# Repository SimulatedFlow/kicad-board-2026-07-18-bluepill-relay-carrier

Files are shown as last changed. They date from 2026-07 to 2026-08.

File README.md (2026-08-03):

# 2026-07-18-bluepill-relay-carrier

<!-- SF-STORE-BLOCK:BEGIN -->
## 🛒 Source-available — see before you buy

This repository contains the **full design files** of a commercial hardware board. It is **source-available, not open source**: read it, evaluate it, then buy a license to use it. See **LICENSE.md (source-available, purchase required)**.

**Get it / Buy:**
- eBay store — all our boards and PCB art: https://www.ebay.de/usr/simula-9
- Merch shop (dev & gaming): https://simulatedflow.myspreadshop.de
- Merch shop (Synthetica / EDM): https://synthetica.myspreadshop.de
- Direct / invoice (Simulated Flow UG): simulatedflow@gmail.com

_This board has no eBay item number of its own listed here — the store link above holds all current listings._

### 📬 **Free Board Documentation & Firmware Pack**

Schematics, BOMs and example-firmware docs for our STM32 carrier boards. Get it by joining the newsletter — plus a heads-up when something new ships. Double opt-in, unsubscribe in one click, no address sharing.

👉 **[Get the free pack](https://simulatedflow.teufel-engineering.com/newsletter/hardware/?q=gh)**

_© 2026 Simulated Flow UG. All rights reserved._
<!-- SF-STORE-BLOCK:END -->

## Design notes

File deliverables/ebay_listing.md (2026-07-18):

# BluePill-Relay-Carrier - Leerplatine fuer STM32 Bluepill (handloetbar, THT-Bausatz-Basis)

Robuste 2-Kanal-Relaisträgerplatine für die STM32 Bluepill mit Sensor-Schnittstelle und galvanischer Absicherung.

## Highlights
- Komplett von Hand loetbar (THT / grosse Bauteile, kein SMD-Feinpitch)
- Passt direkt auf die STM32 'Bluepill' (2x 20-Pin-Buchsenleiste, 22,86 mm Reihenabstand)
- Schraubklemmen am Platinenrand - Kabel sauber nach aussen
- 4x M3-Befestigungsbohrungen fuer gaengige Gehaeuse
- 4-lagig (durchgehende GND- + Versorgungs-Plane, stoerarm/EMV-freundlich)

**Passendes Gehaeuse:** 80x70mm DIN-Hutschienen-Gehäuse (z. B. CamdenBoss CNMB/3)

## Einsatzzweck
Existierende Trägerplatinen sind oft überladene Alleskönner oder billige Steckbrett-Kopien. Dieses Board bietet Bastlern eine saubere, extrem robuste und handlötbare Hutschienen-Plattform für zwei Relais ohne Kabelsalat.

## Bestueckung (ca. 21 Bauteile laut Stueckliste)
- C1: 100uF (x1)
- C2: 100nF (x1)
- D1: 1N4007 (x1)
- D2: 1N4007 (x1)
- D3: 1N5819 (x1)
- D4: LED_RED (x1)
- D5: LED_GRN (x1)
- J1: 5V_IN (x1)
- J2: RY1_OUT (x1)
- J3: RY2_OUT (x1)
- J4: SENSOR (x1)
- Q1: 2N3904 (x1)
- Q2: 2N3904 (x1)
- R1: 1k (x1)
- R2: 1k (x1)
- R3: 330 (x1)
- R4: 330 (x1)
- RY1: SRD-05VDC (x1)
- RY2: SRD-05VDC (x1)
- U1: Bluepill_L (x1)
- U2: Bluepill_R (x1)

## Lieferumfang
- 1x unbestueckte Leiterplatte (Fertigung auf Bestellung via PCBWay)
- Schaltplan als PDF + Bestueckungsliste (BOM als CSV) zum Download

**Preis:** 14.9 EUR (unbestueckte Leerplatine, zzgl. Versand)

Fertigung auf Bestellung - Lieferzeit nach PCBWay-Produktion. Gewerblicher Verkauf durch Simulated Flow UG: gesetzliches Widerrufsrecht und Gewaehrleistung gemaess AGB/Impressum. Versand als versicherter Warenversand.

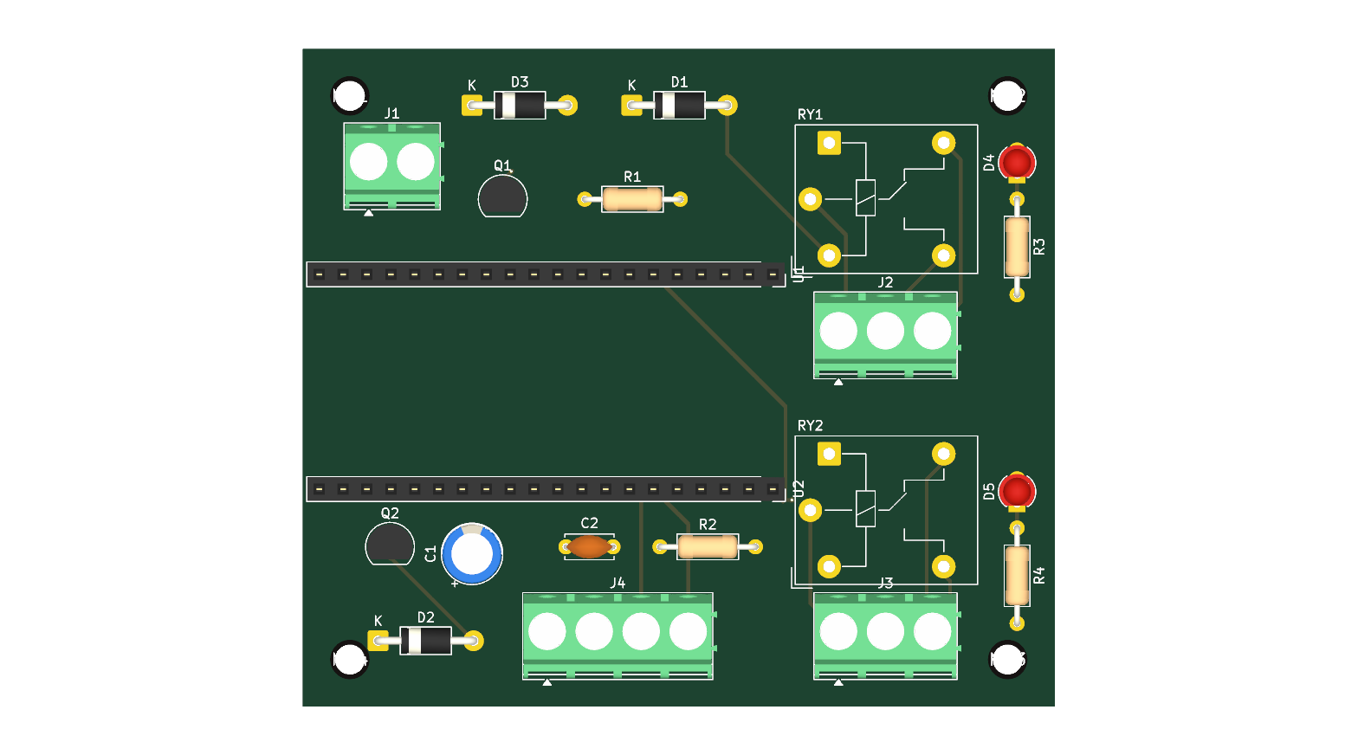
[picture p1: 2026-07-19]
deliverables/render_top.png

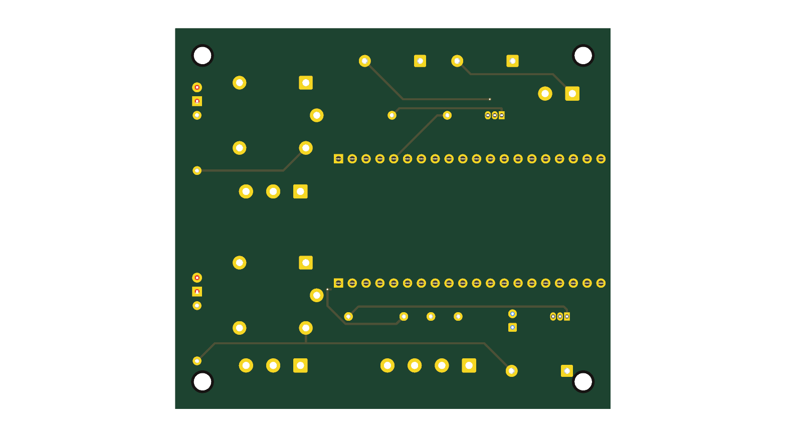
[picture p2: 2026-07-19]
deliverables/render_bottom.png

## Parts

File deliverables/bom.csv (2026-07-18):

Refs | Value | Footprint | Qty | DNP
C1 | 100uF | Capacitor_THT:CP_Radial_D6.3mm_P2.50mm | 1
C2 | 100nF | Capacitor_THT:C_Disc_D5.0mm_W2.5mm_P5.00mm | 1
D1 | 1N4007 | Diode_THT:D_DO-41_SOD81_P10.16mm_Horizontal | 1
D2 | 1N4007 | Diode_THT:D_DO-41_SOD81_P10.16mm_Horizontal | 1
D3 | 1N5819 | Diode_THT:D_DO-41_SOD81_P10.16mm_Horizontal | 1
D4 | LED_RED | LED_THT:LED_D3.0mm | 1
D5 | LED_GRN | LED_THT:LED_D3.0mm | 1
J1 | 5V_IN | TerminalBlock_Phoenix:TerminalBlock_Phoenix_PT-1,5-2-5.0-H_1x02_P5.00mm_Horizontal | 1
J2 | RY1_OUT | TerminalBlock_Phoenix:TerminalBlock_Phoenix_PT-1,5-3-5.0-H_1x03_P5.00mm_Horizontal | 1
J3 | RY2_OUT | TerminalBlock_Phoenix:TerminalBlock_Phoenix_PT-1,5-3-5.0-H_1x03_P5.00mm_Horizontal | 1
J4 | SENSOR | TerminalBlock_Phoenix:TerminalBlock_Phoenix_PT-1,5-4-5.0-H_1x04_P5.00mm_Horizontal | 1
Q1 | 2N3904 | Package_TO_SOT_THT:TO-92_Inline | 1
Q2 | 2N3904 | Package_TO_SOT_THT:TO-92_Inline | 1
R1 | 1k | Resistor_THT:R_Axial_DIN0207_L6.3mm_D2.5mm_P10.16mm_Horizontal | 1
R2 | 1k | Resistor_THT:R_Axial_DIN0207_L6.3mm_D2.5mm_P10.16mm_Horizontal | 1
R3 | 330 | Resistor_THT:R_Axial_DIN0207_L6.3mm_D2.5mm_P10.16mm_Horizontal | 1
R4 | 330 | Resistor_THT:R_Axial_DIN0207_L6.3mm_D2.5mm_P10.16mm_Horizontal | 1
RY1 | SRD-05VDC | Relay_THT:Relay_SPDT_Hongfa_JQC-3FF_0XX-1Z | 1
RY2 | SRD-05VDC | Relay_THT:Relay_SPDT_Hongfa_JQC-3FF_0XX-1Z | 1
U1 | Bluepill_L | Connector_PinSocket_2.54mm:PinSocket_1x20_P2.54mm_Vertical | 1
U2 | Bluepill_R | Connector_PinSocket_2.54mm:PinSocket_1x20_P2.54mm_Vertical | 1

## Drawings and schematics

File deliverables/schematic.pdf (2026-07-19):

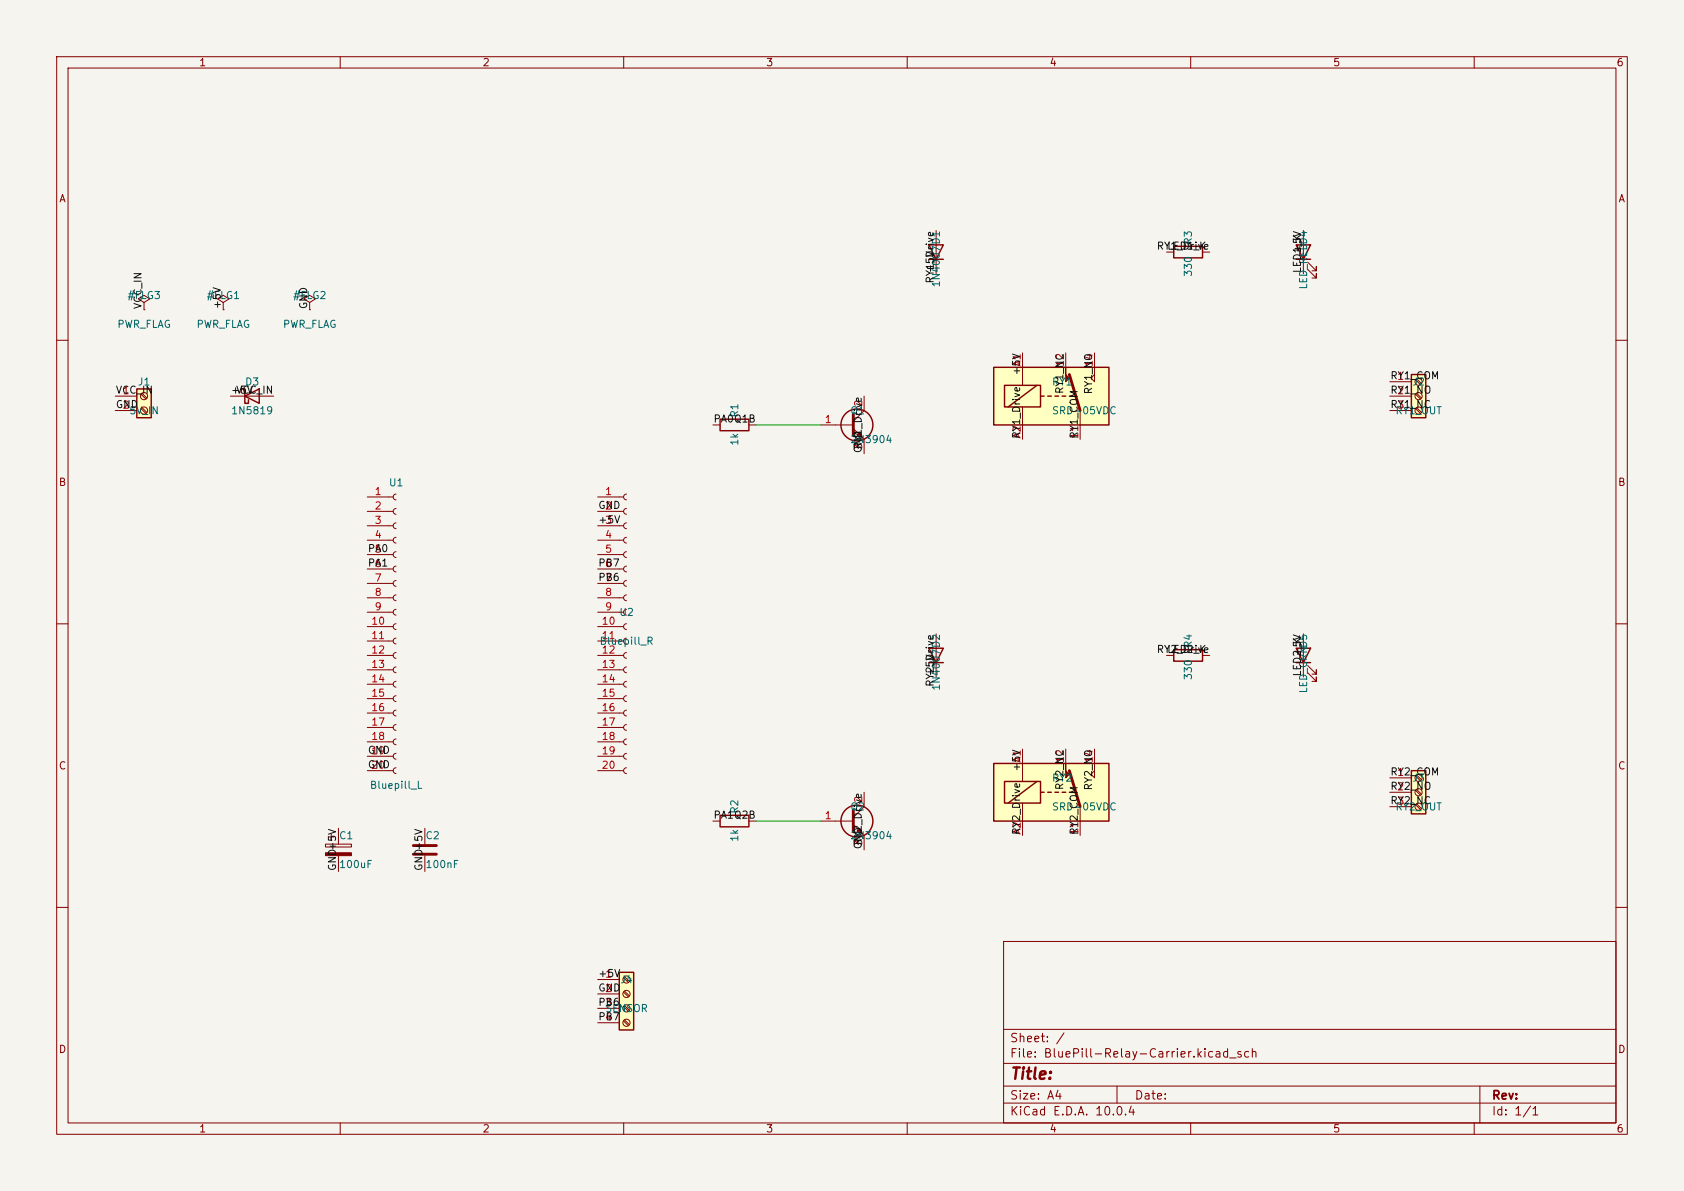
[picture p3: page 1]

Sheet: /
File: BluePill-Relay-Carrier.kicad_sch
Title:

Size: A4 | Rev:
KiCad E.D.A. 10.0.4 | Id: 1/1

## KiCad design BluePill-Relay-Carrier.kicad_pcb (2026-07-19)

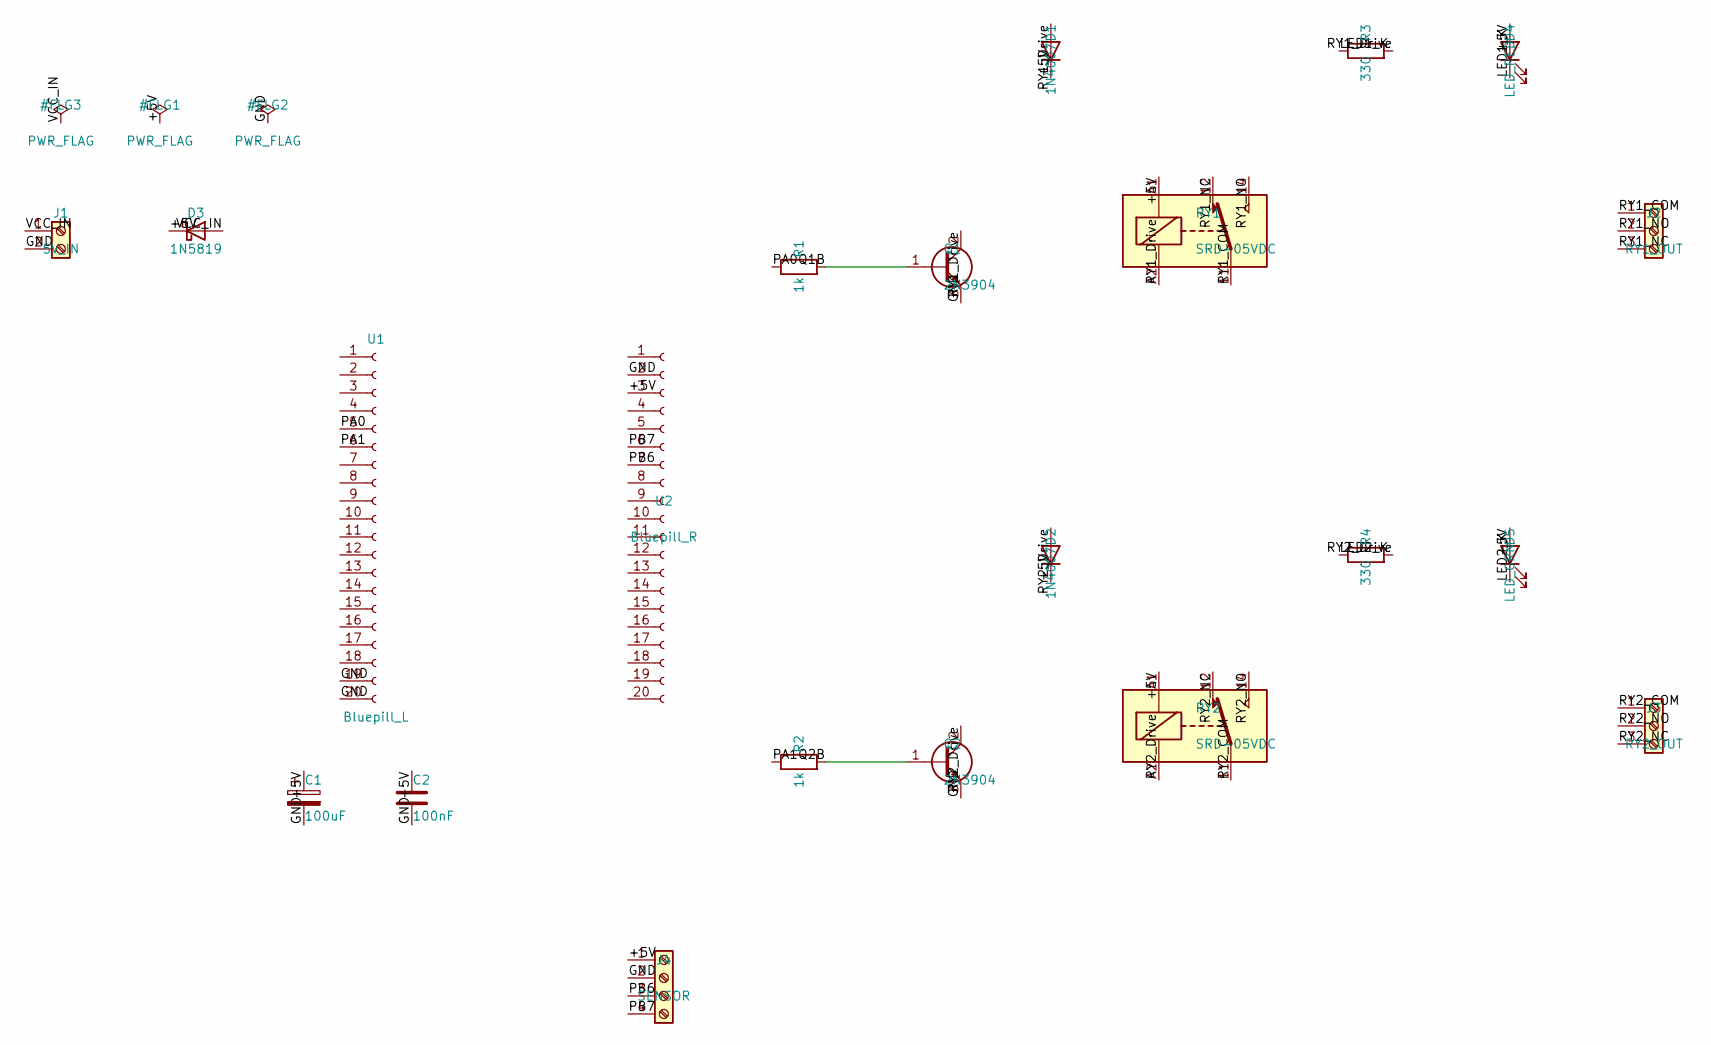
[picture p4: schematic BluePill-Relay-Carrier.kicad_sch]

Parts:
C1: 100uF; CP_Radial_D6.3mm_P2.50mm
C2: 100nF; C_Disc_D5.0mm_W2.5mm_P5.00mm
D1, D2: 1N4007; D_DO-41_SOD81_P10.16mm_Horizontal
D3: 1N5819; D_DO-41_SOD81_P10.16mm_Horizontal
D4: LED_RED; LED_D3.0mm
D5: LED_GRN; LED_D3.0mm
J1: 5V_IN; TerminalBlock_Phoenix_PT-1,5-2-5.0-H_1x02_P5.00mm_Horizontal
J2: RY1_OUT; TerminalBlock_Phoenix_PT-1,5-3-5.0-H_1x03_P5.00mm_Horizontal
J3: RY2_OUT; TerminalBlock_Phoenix_PT-1,5-3-5.0-H_1x03_P5.00mm_Horizontal
J4: SENSOR; TerminalBlock_Phoenix_PT-1,5-4-5.0-H_1x04_P5.00mm_Horizontal
Q1, Q2: 2N3904; TO-92_Inline
R1, R2: 1k; R_Axial_DIN0207_L6.3mm_D2.5mm_P10.16mm_Horizontal
R3, R4: 330; R_Axial_DIN0207_L6.3mm_D2.5mm_P10.16mm_Horizontal
RY1, RY2: SRD-05VDC; Relay_SPDT_Hongfa_JQC-3FF_0XX-1Z
U1: Bluepill_L; PinSocket_1x20_P2.54mm_Vertical
U2: Bluepill_R; PinSocket_1x20_P2.54mm_Vertical

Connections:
+5V: C1.1, C2.1, D1.1 (K), D2.1 (K), D3.1 (K), D4.2 (A), D5.2 (A), J4.1, RY1.A1, RY2.A1, U2.3
GND: C1.2, C2.2, J1.2, J4.2, Q1.3 (E), Q2.3 (E), U1.19, U1.20, U2.2
LED1_K: D4.1 (K), R3.1
LED2_K: D5.1 (K), R4.1
PA0: R1.1, U1.5
PA1: R2.1, U1.6
PB6: J4.3, U2.7
PB7: J4.4, U2.6
Q1B: Q1.1 (B), R1.2
Q2B: Q2.1 (B), R2.2
RY1_COM: J2.1, RY1.11
RY1_Drive: D1.2 (A), Q1.2 (C), R3.2, RY1.A2
RY1_NC: J2.3, RY1.12
RY1_NO: J2.2, RY1.14
RY2_COM: J3.1, RY2.11
RY2_Drive: D2.2 (A), Q2.2 (C), R4.2, RY2.A2
RY2_NC: J3.3, RY2.12
RY2_NO: J3.2, RY2.14
VCC_IN: D3.2 (A), J1.1

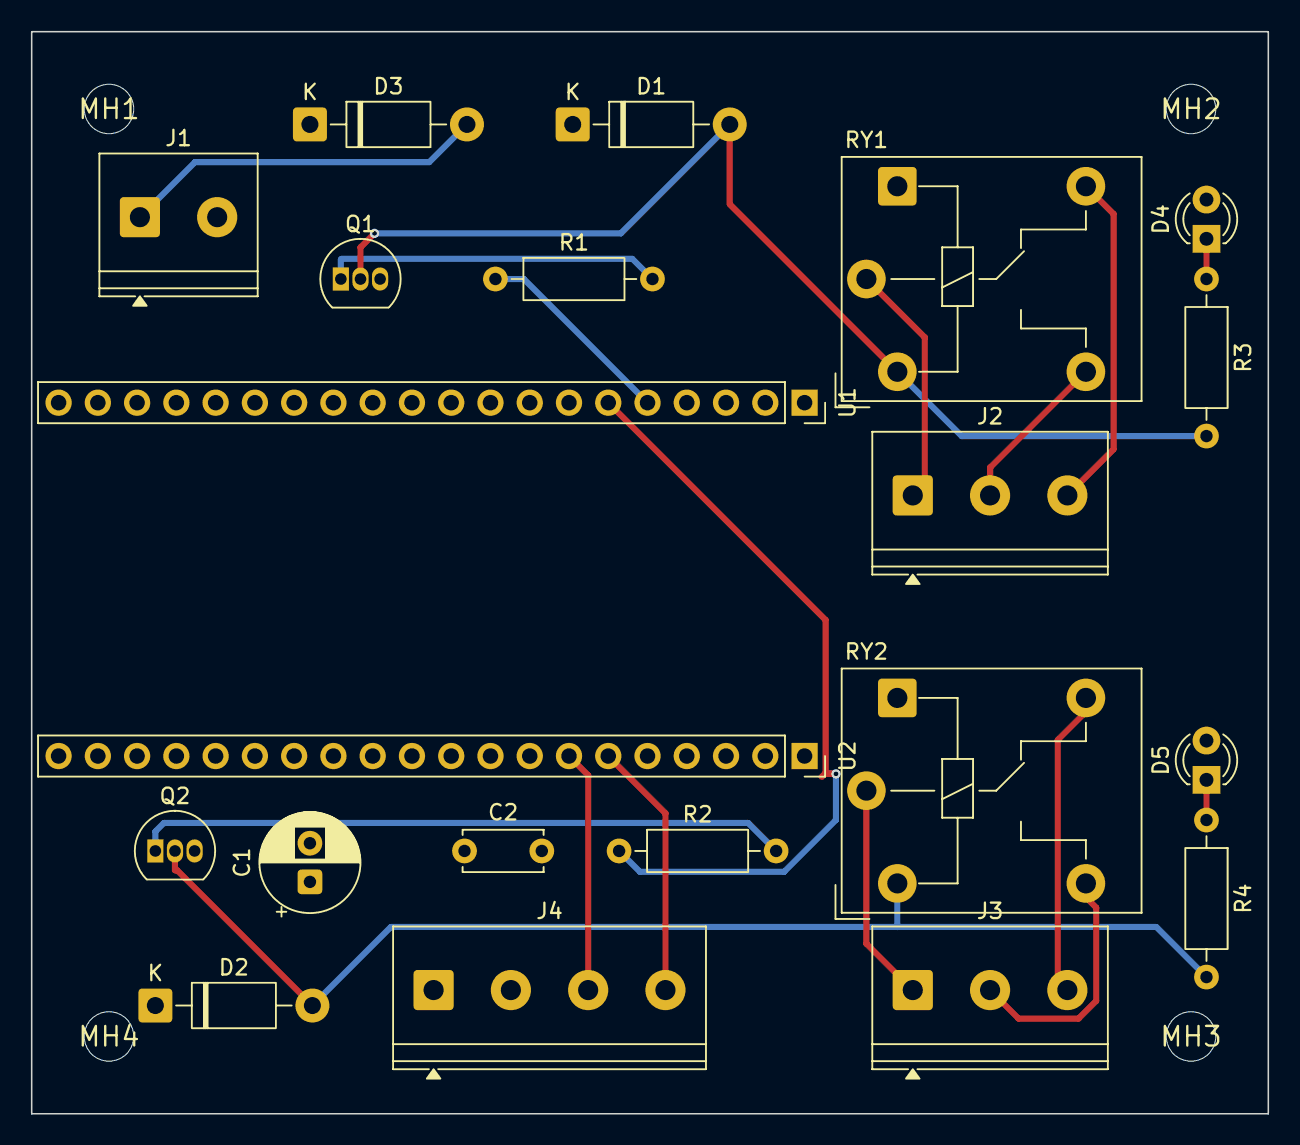
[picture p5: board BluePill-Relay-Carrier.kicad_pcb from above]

Board: 4 copper layers, 80.0 x 70.0 mm, 25 parts (0 on the bottom side), 19 nets.

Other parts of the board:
MH1, MH2, MH3, MH4: MountingHole_3.2mm

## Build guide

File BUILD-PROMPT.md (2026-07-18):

```json
{
  "board_name": "BluePill-Relay-Carrier",
  "one_liner": "Robuste 2-Kanal-Relaisträgerplatine für die STM32 Bluepill mit Sensor-Schnittstelle und galvanischer Absicherung.",
  "market_gap": "Existierende Trägerplatinen sind oft überladene Alleskönner oder billige Steckbrett-Kopien. Dieses Board bietet Bastlern eine saubere, extrem robuste und handlötbare Hutschienen-Plattform für zwei Relais ohne Kabelsalat.",
  "confidence": "high",
  "price_eur": 14.90,
  "target_enclosure": "80x70mm DIN-Hutschienen-Gehäuse (z. B. CamdenBoss CNMB/3)",
  "injection_notes": "keine"
}
```

## BUILD-PROMPT

### Name & Ziel
**BluePill-Relay-Carrier** – Eine handlötbare Trägerplatine (Carrier Board) für das beliebte STM32F103-„Bluepill"-Entwicklungsboard, ausgelegt auf genau eine Kernfunktion: Sicheres, robustes Schalten von zwei Relais und das Auslesen eines externen Sensors im industrienahen oder Hausautomations-Bereich.

---

### 1. HARTE DFM-Vorgaben (Handlöt-Tauglichkeit)
- **Komplexitätsgrenze:** Maximal 19 Bauteile gesamt – extrem luftiges Layout für fehlerfreies Routing und einfaches Löten.
- **Technologie:** Reine THT-Bauweise (Through-Hole Technology). Keine SMD-Bauteile, um den Einstieg für Bastler so einfach wie möglich zu machen.
- **Leiterbahnen & Abstände:** 
  - Standard-Signalleitungen: Breite $\ge 0.4\,\text{mm}$, Clearance $\ge 0.3\,\text{mm}$.
  - Stromversorgung (5V/GND): Breite $\ge 1.0\,\text{mm}$.
  - Relais-Lastpfade: Breite $\ge 1.5\,\text{mm}$ (ausgelegt für bis zu 5A Laststrom).
- **Lagen-Stackup (4 Lagen):**
  - `F.Cu` (Top-Signal & High-Voltage Lastpfade)
  - `In1.Cu` (Durchgehende GND-Plane für hervorragende EMV und Rauschunterdrückung)
  - `In2.Cu` (Durchgehende 5V-Versorgungs-Plane)
  - `B.Cu` (Bottom-Signal & zusätzliche Relais-Leiterbahnen)

---

### 2. Mechanische Spezifikationen
- **Platinengröße:** Exakt $80.0\,\text{mm} \times 70.0\,\text{mm}$ (rechteckig, perfekt passend für Standard-Hutschienenhalterungen).
- **Befestigungsbohrungen:** 4× M3-Bohrungen (Durchmesser $3.2\,\text{mm}$) an den Koordinaten:
  - Loch 1: $(5.0\,\text{mm}, 5.0\,\text{mm})$
  - Loch 2: $(75.0\,\text{mm}, 5.0\,\text{mm})$
  - Loch 3: $(75.0\,\text{mm}, 65.0\,\text{mm})$
  - Loch 4: $(5.0\,\text{mm}, 65.0\,\text{mm})$
  - **Keepout:** $6.0\,\text{mm}$ Kreisdurchmesser um jedes Loch herum (keine Leiterbahnen oder Kupferflächen).

---

### 3. Stückliste (BOM) & KiCad-Footprints (19 Bauteile)

| RefDerig | Bauteil | KiCad-Symbol | KiCad-Footprint | Beschreibung |
| :--- | :--- | :--- | :--- | :--- |
| **U1, U2** | 2x 20-Pin Buchsenleiste | `Connector:Conn_01x20_Socket` | `Connector_PinSocket_2.54mm:PinSocket_1x20_P2.54mm_Vertical` | Sockel für das Bluepill-Board (Abstand der beiden Reihen zueinander: exakt **0.9″ / 22.86 mm**) |
| **RY1, RY2** | 2x Print-Relais (5V) | `Relay:Relay_SPDT` | `Relay_THT:Relay_SPDT_Sanyou_SRD_Series_Form_C` | Standard-Hobby-Relais (z. B. Songle SRD-05VDC-SL-C) |
| **Q1, Q2** | 2x NPN-Transistor | `Device:Q_NPN_EBC` | `Package_TO_SOT_THT:TO-92_Inline` | BC547 oder 2N3904 zur Ansteuerung der Relaisspulen |
| **D1, D2** | 2x Freilaufdiode | `Device:D` | `Diode_THT:D_DO-41_SOD81_P10.16mm_Horizontal` | 1N4007 Diode (Schutz vor Induktionsspannung) |
| **D3** | 1x Schottky-Diode | `Device:D_Schottky` | `Diode_THT:D_DO-41_SOD81_P10.16mm_Horizontal` | 1N5819 (Verpolungsschutz für 5V-Eingang) |
| **R1, R2** | 2x Widerstand 1kΩ | `Device:R` | `Resistor_THT:R_Axial_DIN0207_L6.3mm_D2.5mm_P10.16mm_Horizontal` | Basis-Vorwiderstände für Q1 und Q2 |
| **R3, R4** | 2x Widerstand 330Ω | `Device:R` | `Resistor_THT:R_Axial_DIN0207_L6.3mm_D2.5mm_P10.16mm_Horizontal` | Vorwiderstände für die Status-LEDs |
| **D4, D5** | 2x LED (3mm oder 5mm) | `Device:LED` | `LED_THT:LED_D3.0mm` | Rote/Grüne THT-LEDs zur Visualisierung des Relais-Schaltzustands |
| **C1** | 1x Elko $100\,\mu\text{F}$ | `Device:C_Polarized` | `CP_Radial_D6.3mm_P2.50mm` | Bulk-Kondensator zur Glättung der 5V-Schiene |
| **C2** | 1x Keramikkondensator $100\,\text{nF}$| `Device:C` | `C_Disc_D5.0mm_W2.5mm_P5.00mm` | Entkopplungskondensator |
| **J1** | 1x Schraubklemme 2-polig | `Connector:Screw_Terminal_01x02`| `Connector_TerminalBlock:TerminalBlock_Phoenix_PT-1.5_2-G-5.08_1x02_P5.08mm_Horizontal` | Stromeingang 5VDC (an der linken Boardkante platziert) |
| **J2, J3** | 2x Schraubklemme 3-polig | `Connector:Screw_Terminal_01x03`| `Connector_TerminalBlock:TerminalBlock_Phoenix_PT-1.5_3-G-5.08_1x03_P5.08mm_Horizontal` | Relaisausgänge (COM, NO, NC) (an der rechten Boardkante platziert) |
| **J4** | 1x Schraubklemme 4-polig | `Connector:Screw_Terminal_01x04`| `Connector_TerminalBlock:TerminalBlock_Phoenix_PT-1.5_4-G-5.08_1x04_P5.08mm_Horizontal` | Sensor-Schnittstelle (5V, GND, I2C: SDA/SCL oder GPIO) (an der unteren Kante) |

---

### 4. Elektrische Verbindungen & Logik (Netzliste)
- **Power-Input:**
  - `J1` Pin 1 (VCC_IN) $\rightarrow$ Anode von `D3` (Schottky Verpolungsschutz).
  - Kathode von `D3` $\rightarrow$ Net `+5V` (speist Relaisspulen, C1, C2 und den 5V-Pin der Bluepill).
  - `J1` Pin 2 $\rightarrow$ Net `GND` (GND-Ebene).
- **Bluepill-Integration:**
  - Der Bluepill-Sockel (`U1`/`U2`) wird so platziert, dass der 5V-Pin mit `+5V` verbunden ist und die GND-Pins auf das `GND`-Netz gelegt werden. Der interne Regler der Bluepill erzeugt die $3.3\,\text{V}$ für den STM32-Chip.
- **Relaiskanal 1:**
  - Steuerpin von Bluepill (z. B. `PA0`) $\rightarrow$ `R1` ($1\,\text{k}\Omega$) $\rightarrow$ Basis von `Q1` (NPN).
  - Emitter von `Q1` $\rightarrow$ `GND`.
  - Collector von `Q1` $\rightarrow$ Net `RY1_Drive`.
  - Relaisspule `RY1` liegt zwischen `+5V` und `RY1_Drive`.
  - Freilaufdiode `D1` liegt antiparallel zur Spule (Kathode an `+5V`, Anode an `RY1_Drive`).
  - Status-LED `D4` mit Vorwiderstand `R3` ($330\,\Omega$) liegt ebenfalls parallel zur Spule (Anode an `+5V`, Kathode über `R3` an `RY1_Drive`).
  - Relaiskontakt-Pins von `RY1` gehen direkt zu `J2` (Pin 1: COM, Pin 2: NO, Pin 3: NC).
- **Relaiskanal 2:**
  - Steuerpin von Bluepill (z. B. `PA1`) $\rightarrow$ `R2` ($1\,\text{k}\Omega$) $\rightarrow$ Basis von `Q2` (NPN).
  - Emitter von `Q2` $\rightarrow$ `GND`.
  - Collector von `Q2` $\rightarrow$ Net `RY2_Drive`.
  - Relaisspule `RY2` liegt zwischen `+5V` und `RY2_Drive`.
  - Freilaufdiode `D2` antiparallel zur Spule (Kathode an `+5V`, Anode an `RY2_Drive`).
  - Status-LED `D5` mit Vorwiderstand `R4` ($330\,\Omega$) parallel zur Spule (Anode an `+5V`, Kathode über `R4` an `RY2_Drive`).
  - Relaiskontakt-Pins von `RY2` gehen direkt zu `J3` (Pin 1: COM, Pin 2: NO, Pin 3: NC).
- **Sensor-Schnittstelle:**
  - `J4` Pin 1 $\rightarrow$ `+5V` / `+3.3V` (wählbar oder fest verdrahtet).
  - `J4` Pin 2 $\rightarrow$ `GND`.
  - `J4` Pin 3 $\rightarrow$ Bluepill `PB6` (I2C1_SCL oder digitaler Pin).
  - `J4` Pin 4 $\rightarrow$ Bluepill `PB7` (I2C1_SDA oder digitaler Pin).

---

### 5. Layout- & Routingvorgaben für den Bau-Agenten
1. **Projekt anlegen:** Erzeuge ein neues KiCad-Projekt im Arbeitsverzeichnis.
2. **Schaltplan zeichnen:** Setze obiges Schaltungsdesign um. Verwende globale Labels für saubere Strukturierung.
3. **Leiterplatten-Umriss:** Ziehe ein Rechteck mit den Maßen $80.0\,\text{mm} \times 70.0\,\text{mm}$ auf dem Layer `Edge.Cuts`. Platziere die vier M3-Bohrungen wie spezifiziert.
4. **Platzierung:**
   - Setze die Bluepill-Sockel `U1, U2` mittig auf das Board.
   - Platziere `J1` (Power) an der linken Kante, `J4` (Sensor) an der Unterkante.
   - Setze `RY1, RY2` sowie deren Schraubklemmen `J2, J3` an die rechte Kante, sodass die Hochspannungsleitungen maximal kurz sind.
   - Die Treiberstufen (Transistoren, Dioden, Vorwiderstände) nahe bei den Relais platzieren.
   - Die Status-LEDs `D4, D5` gut sichtbar am oberen Rand positionieren.
5. **Kupferflächen & Planes:** Erzeuge durchgehende GND-Zonen auf `In1.Cu` sowie `B.Cu` und eine 5V-Zone auf `In2.Cu`.
6. **Isolationsschlitz (Kriechstrecke):** Zeichne im Edge.Cuts-Layer eine nicht-metallisierte Ausfräsung (Slot, Breite $1.5\,\text{mm}$) unter den Relaiskontakten hindurch, um den Laststromkreis (230V-tauglich) galvanisch und physisch vom Niederspannungs-Steuerstromkreis (5V/3.3V) der Bluepill zu trennen.
7. **Routing:** Starte das Freerouting-Plugin für optimales, kreuzungsfreies 4-Layer-Autorouting unter Einhaltung der Leiterbahnbreiten.
8. **Prüfung & Export:** Führe den Design Rule Check (DRC) fehlerfrei aus und exportiere alle Gerberdaten, Bohrdateien sowie Bestückungsdaten sauber in das Verzeichnis `./gerbers`.

---

*Hinweis für den Bau-Agenten: Bitte führe diese Schritte strukturiert aus und gib am Ende ein ehrliches, kurzes Feedback darüber, was beim automatisierten Generieren und Routen der Platine geklappt hat.*

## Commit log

2026-07-18 auto-backup 2026-07-18 21:26:19
    [BluePill-Relay-Carrier.kicad_pcb, BluePill-Relay-Carrier.kicad_sch]
2026-07-18 auto-backup 2026-07-18 22:26:17
    [BluePill-Relay-Carrier-B_Courtyard.gbr, BluePill-Relay-Carrier-B_Cu.gbl, BluePill-Relay-Carrier-B_Fab.gbr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]
2026-07-19 auto-backup 2026-07-19 21:26:19
    [BluePill-Relay-Carrier-B_Courtyard.gbr, BluePill-Relay-Carrier-B_Cu.gbl, BluePill-Relay-Carrier-B_Fab.gbr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]
